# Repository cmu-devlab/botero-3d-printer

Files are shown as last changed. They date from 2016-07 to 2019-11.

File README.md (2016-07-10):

# Botero 3D Printer Construction
******WORK-IN-PROGRESS******
  - Contents
    - `./drivers`: USB drivers for the Arduino Mega with CH340g chipset
    - `./firmware`: files for loading firmware onto the Arduino Mega + RAMPS 1.4 board
    - `./printer-parts`: laser-cut and 3d printable part files
  - Guides
    - [Bill of Materials](https://docs.google.com/spreadsheets/d/1qfAnqGb2Y4jCnc3KZLQFH8dfTMAcHStBsM3m4sgjOxE/edit?usp=sharing)
    - [Preliminary (incomplete) Instructions](https://docs.google.com/document/d/1Rjcu9FiFy42U2eL0eWIAQUI9wFf0EVY7zgJ4SKwblW4/edit)

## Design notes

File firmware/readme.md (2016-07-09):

# Firmware Setup Instructions
- Visit https://www.repetier.com/firmware/v092/
- Upload the `repetier-firmware-base-config-v092_9.json` file. You can use these settings to help calibrate your printer and its dimensions later
- Go through the configuration wizard and set the BAUD_RATE to 115200 for compatability with Macs and Windows OS. If you are only using Windows-based OS, you can use 250000.

* If you're having trouble connecting to device in Repeiter Host after installing the printer firmware, ensure your firmware is compiled with a `BAUD_RATE` of `115200`.

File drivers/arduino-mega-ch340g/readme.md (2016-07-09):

# Arduino CH340g Driver Installation
These drivers are available for convenience to install the chipset CH340/1 arduino boards.

### Mac OS >= 10.9 Instructions
  - Plug in the device.
  - Locate and install the driver `CH34x_Install.pkg` within the Mac OS drivers folder `./path_to_repository/drivers/arduino-mega-ch340g/mac-osx-10_9-or-higher`.
  - Once finished restart your computer.
  - Plug in your device if it isn't already plugged in.
  - Open a terminal window and type `ls /dev/tty*`. 
  - If the driver properly installed you should see a device like `tty.wchusbserial`. 

### Windows >= 8 Instructions
  - `Note: This driver is for CH340, CH340G & CH341 (USB-SERIAL chip) V3.4 Driver Version = 08/08/2014, 3.4.2014.08.`
  - Plug the Arduino Mega into USB port
  - Open Device Manager > under `Other Devices`, there should be something recognized as "USB2.0-Serial" with an exclamation mark. Right click and select `Update Driver Software`.
  - Select `Browse my computer for driver software`
  - Locate and select the top-level driver folder in the Windows 8 or greater folder of this direction: `./path_to_repository/drivers/win8-or-greater/CH341SER`
  - Complete the installation - once the installer finishes, you should see USB-SERIAL CH340 as being recognized.
  - In Device Manager, this device should be listed under `Ports (COM & LPT)`.

### Sources
- Original Drivers can be found on http://www.wch.cn/download/CH341SER_ZIP.html
- Windows >= 8 Instructions :http://www.arduined.eu/ch340-windows-8-driver-download/

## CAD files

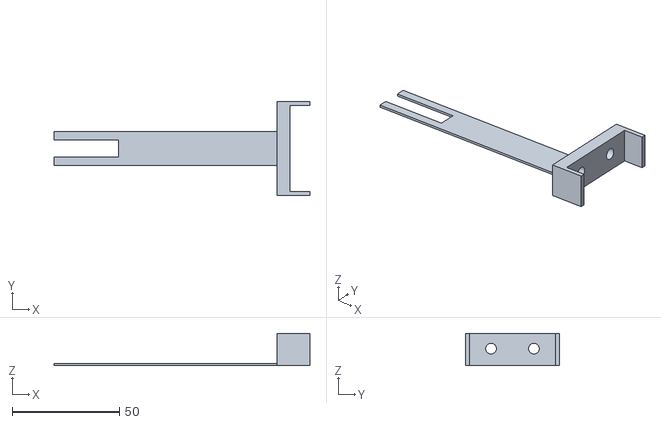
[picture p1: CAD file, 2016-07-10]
printer-parts/alignment-guide/alignment_guide.stl
119.4 x 44.0 x 15.0

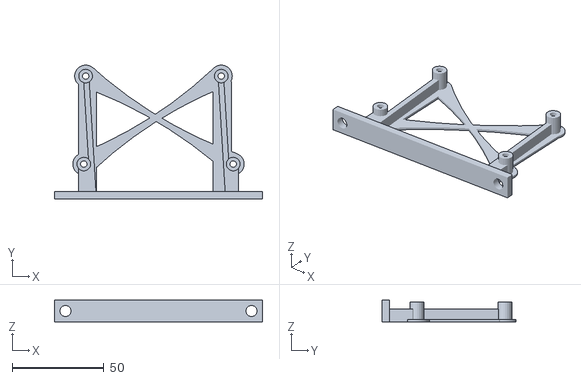
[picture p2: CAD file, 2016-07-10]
printer-parts/arduino-t-slot-mount/Arduino_T-Slot_Mount_mod1.stl
113.5 x 73.0 x 12.0

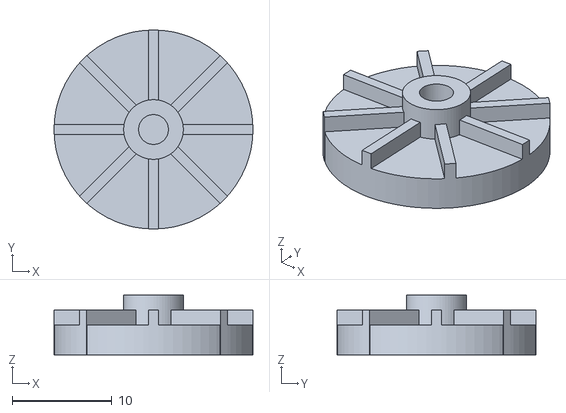
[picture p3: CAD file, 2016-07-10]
printer-parts/end-stop-bumper/endstop_bumper_v2.stl
20.0 x 20.0 x 6.00

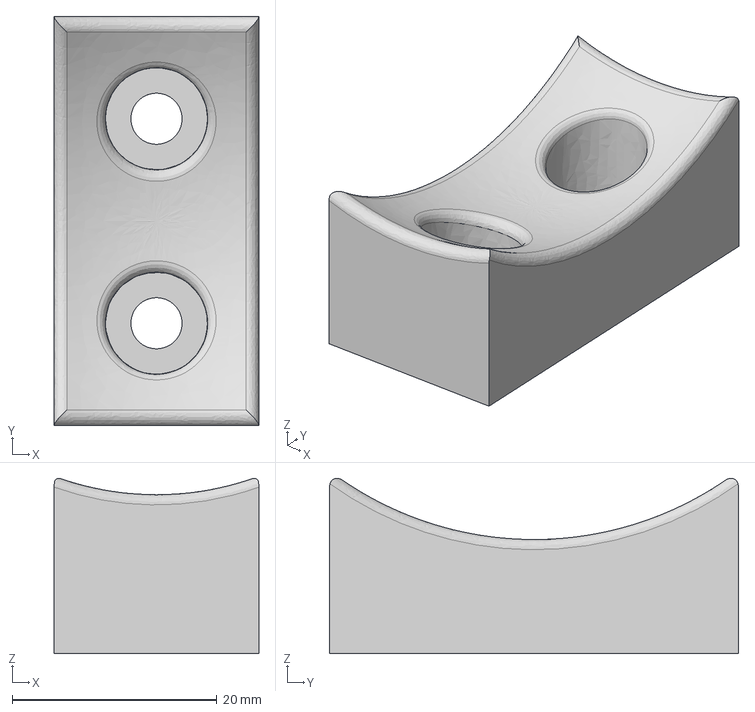
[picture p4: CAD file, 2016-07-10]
printer-parts/foot/tennis-ball-foot-holder/tennis_ball_foot_bracket_v1 v1.iges
20.0 x 40.0 x 17.1 mm

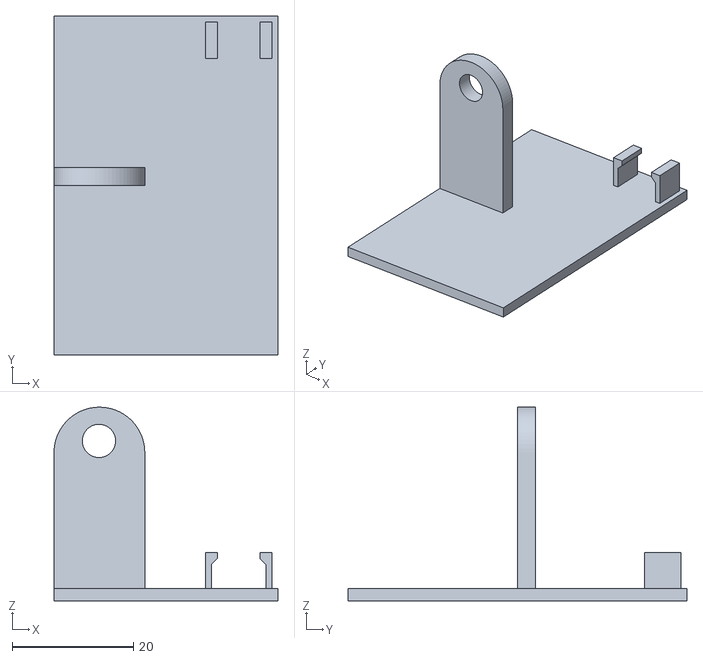
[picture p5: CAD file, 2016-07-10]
printer-parts/led-holder/LED_plate_v3.stl
37.0 x 56.0 x 32.0

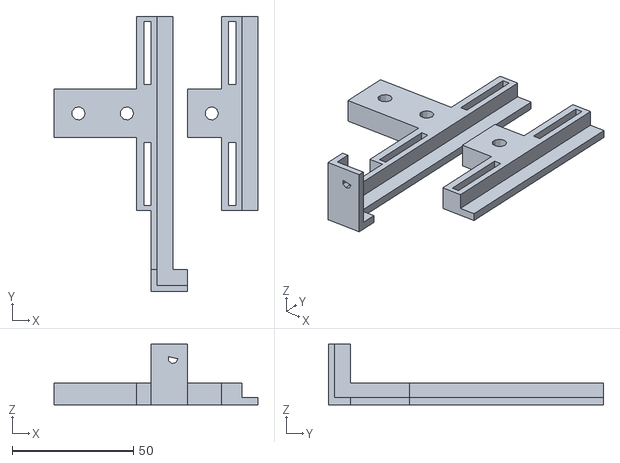
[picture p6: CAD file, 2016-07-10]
printer-parts/power-supply-holder/ps_holder4.stl
84.0 x 113.5 x 25.0

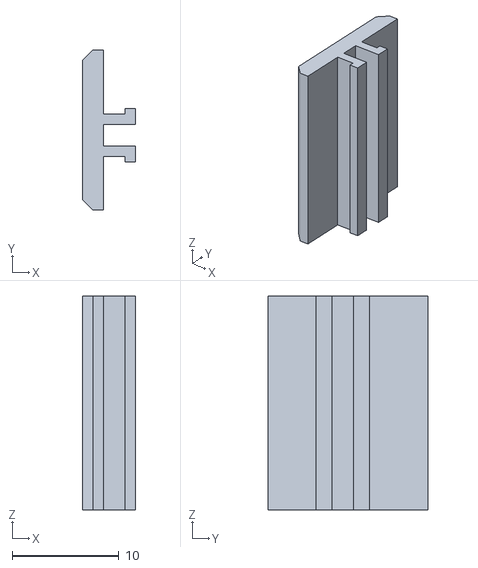
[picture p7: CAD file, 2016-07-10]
printer-parts/t-slot-cable-cover/t-slot_cable_cover.stl
5.00 x 15.0 x 20.0

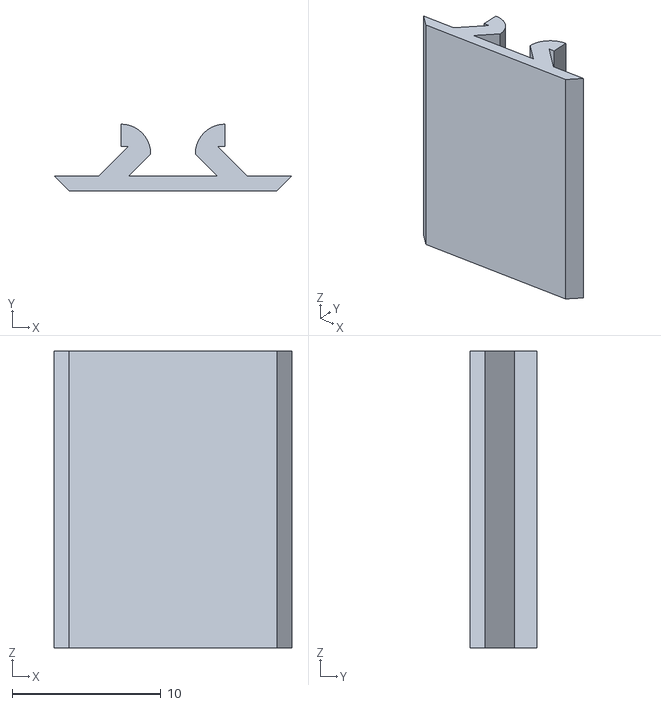
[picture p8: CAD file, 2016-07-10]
printer-parts/v-slot-cable-cover/V-slot_2020_cable_cover.STL
16.0 x 4.50 x 20.0

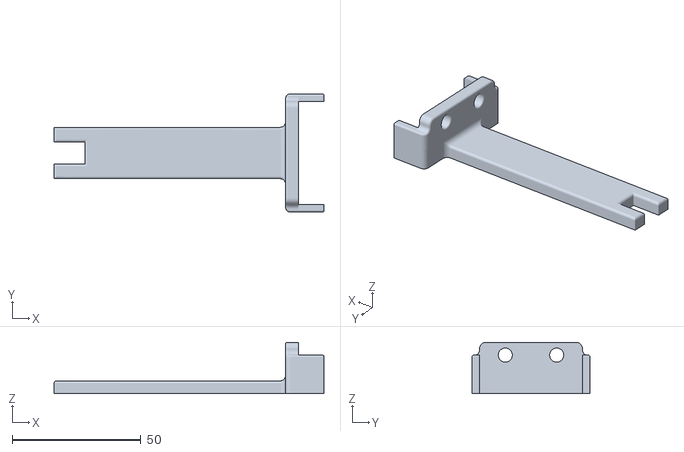
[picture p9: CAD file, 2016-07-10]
printer-parts/z-axis-centering-jig/z_axis_centering_jig_v1.stl
105.0 x 46.0 x 20.0

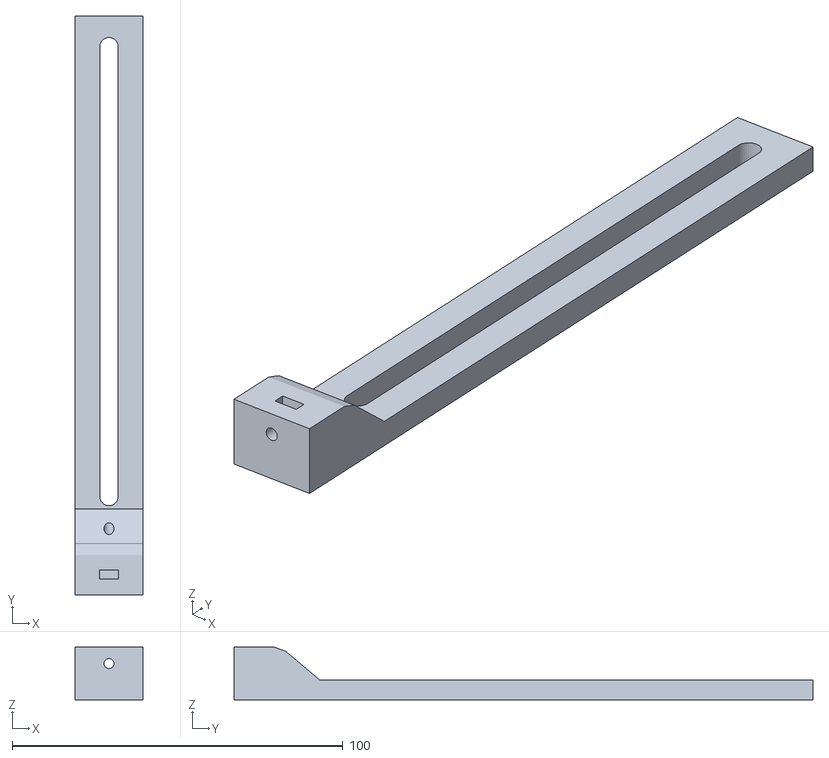
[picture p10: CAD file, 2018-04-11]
printer-parts/z-axis-end-stop-plunger/z-endstop-mr/z-endstop-v1.stl
20.5 x 175.0 x 16.0

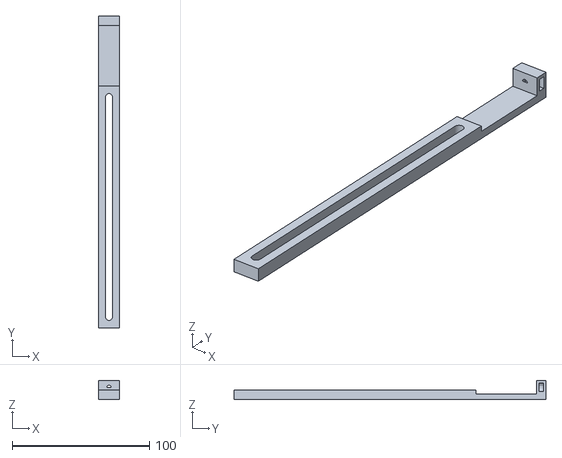
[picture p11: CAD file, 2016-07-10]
printer-parts/z-axis-end-stop-plunger/z_endstop_plunger.stl
15.0 x 227.0 x 14.0

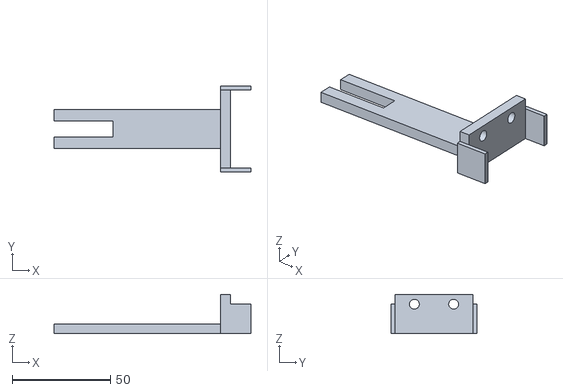
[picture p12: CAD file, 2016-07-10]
printer-parts/alignment-guide/alignment_guide_v2.stl
100.4 x 44.0 x 20.0

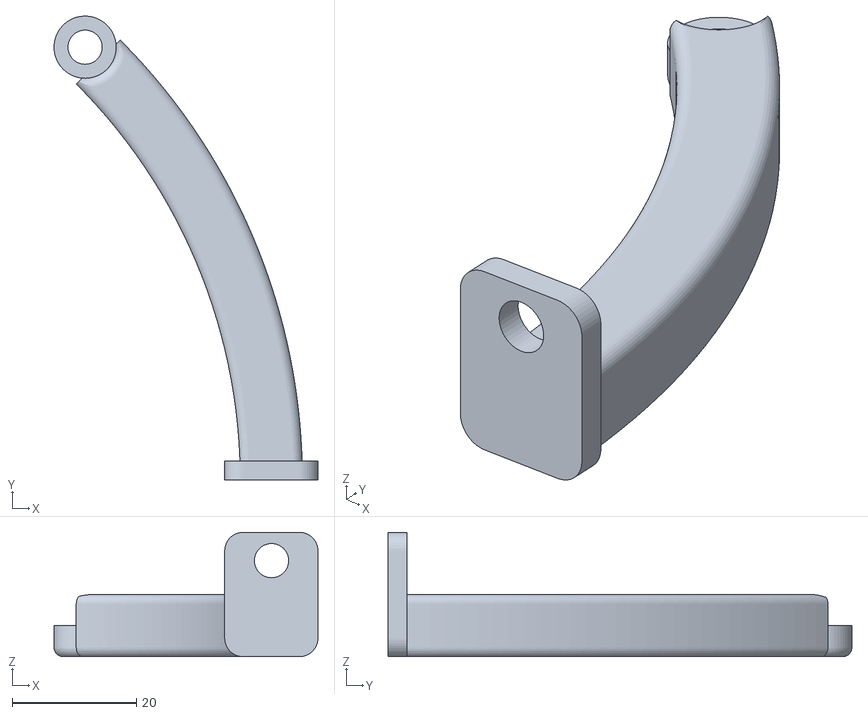
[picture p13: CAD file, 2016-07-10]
printer-parts/led-holder/LED_arm1_v4.stl
42.4 x 74.6 x 20.0

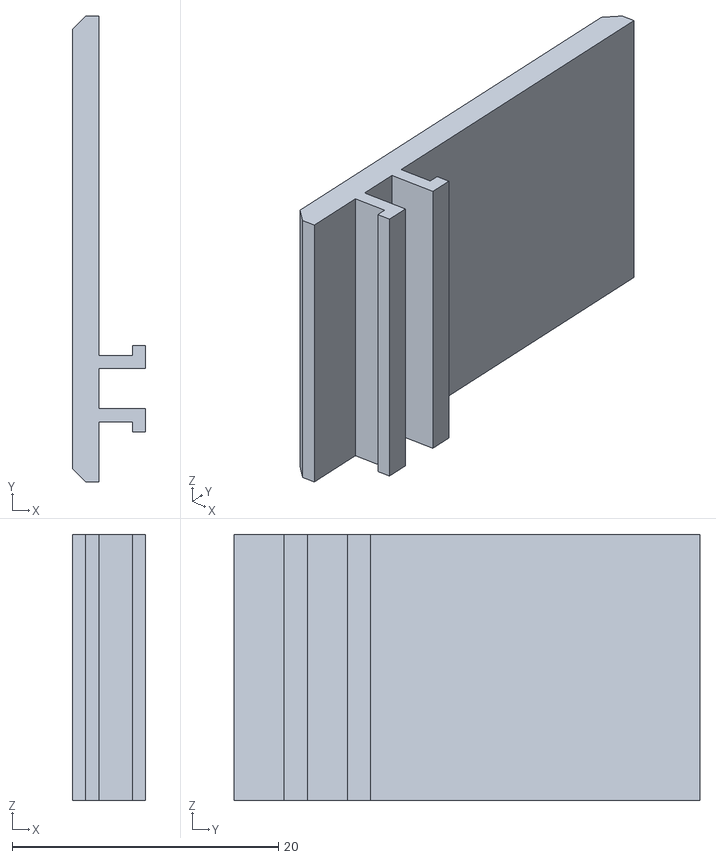
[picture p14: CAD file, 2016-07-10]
printer-parts/t-slot-cable-cover/t-slot_cable_cover_v2_double_wide.stl
5.50 x 35.0 x 20.0

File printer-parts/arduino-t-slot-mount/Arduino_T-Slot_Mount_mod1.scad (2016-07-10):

holes_size = 1.75; // Radius
holes_size_outter = 3.75; // Radius
holes_support = 11;
$fn=100;

difference() {
	union() {
		translate([70.5,0,0]) {
			translate([0,-17,0]) {
				translate([17,0,0])rotate([0,0,180])t_slot();
				cube([10,62,1.3]);
			}
			translate([6.8,-18,0])rotate([0,0,3.5])cube([3,63,holes_support*.65]);
		}

		translate([-3,0,0]) {
			translate([0,-17,0]) {
				translate([-3,0,0])t_slot();
				cube([10,62,1.3]);
			}
			translate([6.8,-18,0])rotate([0,0,3.5])cube([3,63,holes_support*.65]);
		}

		translate([3,-19,0])cube([75,4,12]);

		#translate([-3,-19,0])cube([7.5,18,7.15]);
		#translate([77,-19,0])cube([7.5,18,7.15]);

		arduino_holes();

		linear_extrude(height=1.3)barbell([75,48],[0,0],6,6,230,230);
		linear_extrude(height=1.3)barbell([81.5,0],[1,48],6,6,240,240);
	}
	union() {
		// Holes
		//RB
			cylinder(r=holes_size,h=holes_support, $fn=20);
		//LB
			translate([1,48,0])cylinder(r=holes_size,h=holes_support, $fn=20);
		//RT
			translate([81.5,0,0])cylinder(r=holes_size,h=holes_support, $fn=20);
		//LT
			translate([75,48,0])cylinder(r=holes_size,h=holes_support, $fn=20);
	}
}




module arduino_holes() {
difference() {

union() {
// Outter
//RB
	cylinder(r=holes_size_outter,h=holes_support, $fn=20);
//LB
	translate([1,48,0])cylinder(r=holes_size_outter,h=holes_support, $fn=20);
//RT
	translate([81.5,0,0])cylinder(r=holes_size_outter,h=holes_support, $fn=20);
//LT
	translate([75,48,0])cylinder(r=holes_size_outter,h=holes_support, $fn=20);
}
// Holes
//RB
	cylinder(r=holes_size,h=holes_support, $fn=20);
//LB
	translate([1,48,0])cylinder(r=holes_size,h=holes_support, $fn=20);
//RT
	translate([81.5,0,0])cylinder(r=holes_size,h=holes_support, $fn=20);
//LT
	translate([75,48,0])cylinder(r=holes_size,h=holes_support, $fn=20);
}

}

module t_slot() {

	difference() {
		translate([0,0,6])cube([20,4,12],true);
		translate([-4,3,6])rotate([90,0,0])cylinder(r=3, h=10);
	}

}


module barbell (x1,x2,r1,r2,r3,r4) 
{
	x3=triangulate (x1,x2,r1+r3,r2+r3);
	x4=triangulate (x2,x1,r2+r4,r1+r4);
	render()
	difference ()
	{
		union()
		{
			translate(x1)
			circle (r=r1);
			translate(x2)
			circle(r=r2);
			polygon (points=[x1,x3,x2,x4]);
		}
		translate(x3)
		circle(r=r3,$fa=5);
		translate(x4)
		circle(r=r4,$fa=5);
	}
}

function triangulate (point1, point2, length1, length2) = 
point1 + 
length1*rotated(
atan2(point2[1]-point1[1],point2[0]-point1[0])+
angle(distance(point1,point2),length1,length2));

function distance(point1,point2)=
sqrt((point1[0]-point2[0])*(point1[0]-point2[0])+
(point1[1]-point2[1])*(point1[1]-point2[1]));

function angle(a,b,c) = acos((a*a+b*b-c*c)/(2*a*b)); 

function rotated(a)=[cos(a),sin(a),0];

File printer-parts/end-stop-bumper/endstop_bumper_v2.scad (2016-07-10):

$fn=64;
difference() {
	union() {
		cylinder(r=20/2,h=3);
		cylinder(r=6/2, h=6);
		for (angle=[0:45:359.99]) {
			rotate([0,0,angle]) 
			translate([-10,-0.5,0]) 
				cube([20,1,4.5]);
		}
	}
	translate([0,0,1]) cylinder(r=3.0/2, h=6);
}

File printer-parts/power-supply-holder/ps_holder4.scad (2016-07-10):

ps_slip = 1;
ps_h = 86+ps_slip;
ps_w = 150+ps_slip;
ps_len = 140+ps_slip;
hole_bl = [6,16];
hole_br = [ps_w-30, 6];
hole_tl = [6, ps_h-6];
hole_tr = [ps_w-6, ps_h-6];
hole_diam = 4;
hole_pad = 12;
wall = 3;
beam = 6;
hanger_len = 20; // single wide
hanger_w = 20*2; // two tall
hanger_thick = beam+wall;
hanger_hole_diam = 5.5;
hanger_hole_offset = 10;
hanger_hole_spacing = 20;
strap_w = 30;
strap_margin = 2;
strap_holder_sz = 6;
strap_slot = 3;


module top_mount() {
	difference() {
		translate([-wall,-wall,-wall]) 
		union() {
			// block for bar across
			cube([beam+wall, wall+ps_len/2+hanger_len/2+strap_w, beam+wall]);
			// beam going around corner and up to left hole
			cube([beam+wall+hole_pad/2, beam+wall, hole_bl[1]+hole_pad/2+wall]);
			// right strap holder
			translate([-strap_holder_sz,wall+ps_len/2+hanger_len/2,0])
				difference() {
					cube([strap_holder_sz,strap_w,beam+wall]);
					translate([strap_holder_sz/2-strap_slot/2+wall/2,strap_margin,0])
						cube([strap_slot,strap_w-2*strap_margin,beam+wall]);
				}
			// left strap holder
			translate([-strap_holder_sz,wall+ps_len/2-hanger_len/2-strap_w,0])
				difference() {
					cube([strap_holder_sz,strap_w,beam+wall]);
					translate([strap_holder_sz/2-strap_slot/2+wall/2,strap_margin,0])
						cube([strap_slot,strap_w-2*strap_margin,beam+wall]);
				}
			// hanger
			translate([-(hanger_w), ps_len/2-hanger_len/2+wall, 0]) 
				difference() {
					cube([hanger_w,hanger_len,hanger_thick]);
					for (row = [0:1]) 
						for (col = [0:1])
							translate([
									hanger_hole_offset+row*hanger_hole_spacing, 
									hanger_hole_offset+col*hanger_hole_spacing,0]) 
								cylinder(r=hanger_hole_diam/2, h=hanger_thick);
				}
		}
		// cut out for body of PS
		translate([-ps_slip/2,-ps_slip/2,0]) cube([ps_w,ps_len,ps_h]);
		// cut through so bottom of base is open instead of solid
		translate([beam,beam,-wall]) cube([ps_w-2*beam,ps_len-2*beam,ps_h]);
		// drill mounting hole
		translate([hole_bl[0],0,hole_bl[1]]) rotate([90,0,0]) 
			cylinder(r=hole_diam/2, h=wall);
	}
}

module bottom_mount() {
	difference() {
		translate([-wall,-wall,-wall]) 
		union() {
			// block for bar across
			translate([0,ps_len/2-hanger_len/2-strap_w+wall,0])
				cube([beam+wall, hanger_len+strap_w*2, beam+wall]);
			// right strap holder
			translate([-strap_holder_sz,wall+ps_len/2+hanger_len/2,0])
				difference() {
					cube([strap_holder_sz,strap_w,beam+wall]);
					translate([strap_holder_sz/2-strap_slot/2+wall/2,strap_margin,0])
						cube([strap_slot,strap_w-2*strap_margin,beam+wall]);
				}
			// left strap holder
			translate([-strap_holder_sz,wall+ps_len/2-hanger_len/2-strap_w,0])
				difference() {
					cube([strap_holder_sz,strap_w,beam+wall]);
					translate([strap_holder_sz/2-strap_slot/2+wall/2,strap_margin,0])
						cube([strap_slot,strap_w-2*strap_margin,beam+wall]);
				}
			// hanger
			translate([-hanger_w/2, ps_len/2-hanger_len/2+wall, 0]) 
				difference() {
					cube([hanger_w/2,hanger_len,hanger_thick]);
					translate([-hanger_hole_offset+hanger_hole_spacing, 
									hanger_hole_offset,0]) 
								cylinder(r=hanger_hole_diam/2, h=hanger_thick);
				}
		}
		// cut out for body of PS
		translate([-ps_slip/2,-ps_slip/2,0]) cube([ps_w,ps_len,ps_h]);
		// cut through so bottom of base is open instead of solid
		translate([beam,beam,-wall]) cube([ps_w-2*beam,ps_len-2*beam,ps_h]);
	}
}

top_mount();
// bottom_mount();
translate([35,0,0]) bottom_mount();

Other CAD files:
printer-parts/t-slot-cable-cover/t-slot_cable_cover_v2.stl
printer-parts/t-slot-cable-cover/t-slot_cable_cover_v1.iges
printer-parts/led-holder/LED_arm2_v4.stl
printer-parts/led-holder/led_brackets_v2.stl
printer-parts/z-axis-end-stop-plunger/z_endstop_plunger.scad
printer-parts/alignment-guide/alignment_guide.3dm
printer-parts/alignment-guide/alignment_guide_v2.3dm
printer-parts/foot/tennis-ball-foot-holder/tennis_ball_foot_holder_v1.3dm
printer-parts/led-holder/LED Brackets v3.f3d
printer-parts/led-holder/LED_arm1_v3.stl
printer-parts/led-holder/LED_arm2_v3.stl
printer-parts/previous-designs/z_axis_nut_holder_v4.scad
printer-parts/previous-designs/z_axis_nut_holder_v4.stl
printer-parts/t-slot-cable-cover/t-slot_cable_cover_v2.f3d
printer-parts/t-slot-cable-cover/t-slot_cable_cover_v2_double_wide v0.f3d
printer-parts/z-axis-centering-jig/z-axis_centering_jig_v1.f3d
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

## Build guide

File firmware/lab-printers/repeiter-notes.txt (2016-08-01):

X/Y refer to the

Distortion refers to the region in which the extruder is allowed to move during the printing process

BED_LEFT = DISTORTION_XMIN
BED_WIDTH = DISTORTION_XMAX - DISTORTION_XMIN 

BED_FRONT = DISTORTION_YMIN
BED_DEPTH = DISTORTION_YMAX - DISTORTION_YMIN 

112 0921

IF you want to use 2 heaters (Heat 2 on board / dual extruders) you must disable the fan driving in the firmware.
Namely set `FEATURE_FAN_CONTROL` to 0. 
#define FEATURE_FAN_CONTROL 0

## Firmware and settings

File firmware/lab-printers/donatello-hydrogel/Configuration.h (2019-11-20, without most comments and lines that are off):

#define CONFIGURATION_H
#define NUM_EXTRUDER 2
#define MOTHERBOARD 33
#include "pins.h"
#undef FAN_BOARD_PIN
#define FAN_BOARD_PIN HEATER_2_PIN
#define BOARD_FAN_SPEED 255
#define FAN_THERMO_PIN -1
#define FAN_THERMO_MIN_PWM 128
#define FAN_THERMO_MAX_PWM 255
#define FAN_THERMO_MIN_TEMP 45
#define FAN_THERMO_MAX_TEMP 60
#define FAN_THERMO_THERMISTOR_PIN -1
#define FAN_THERMO_THERMISTOR_TYPE 1
#define BLUETOOTH_SERIAL  -1
#define BLUETOOTH_BAUD  115200
#define MIXING_EXTRUDER 0
#define DRIVE_SYSTEM 0
#define XAXIS_STEPS_PER_MM 160       //OK
#define YAXIS_STEPS_PER_MM 160       //OK
#define ZAXIS_STEPS_PER_MM 800      //OK
#define EXTRUDER_FAN_COOL_TEMP 50
#define PDM_FOR_EXTRUDER 0
#define PDM_FOR_COOLER 0
#define DECOUPLING_TEST_MAX_HOLD_VARIANCE 20
#define DECOUPLING_TEST_MIN_TEMP_RISE 1
#define KILL_IF_SENSOR_DEFECT 0
#define RETRACT_ON_PAUSE 2
#define PAUSE_START_COMMANDS ""
#define PAUSE_END_COMMANDS ""
#define SHARED_EXTRUDER_HEATER 0
#define EXT0_X_OFFSET 0
#define EXT0_Y_OFFSET 0
#define EXT0_Z_OFFSET 0
#define EXT0_STEPS_PER_MM 184    //OK
#define EXT0_TEMPSENSOR_TYPE 1
#define EXT0_TEMPSENSOR_PIN TEMP_0_PIN
#define EXT0_HEATER_PIN HEATER_0_PIN
#define EXT0_STEP_PIN ORIG_E0_STEP_PIN
#define EXT0_DIR_PIN ORIG_E0_DIR_PIN
#define EXT0_INVERSE 1
#define EXT0_ENABLE_PIN ORIG_E0_ENABLE_PIN
#define EXT0_ENABLE_ON 0
#define EXT0_MIRROR_STEPPER 0
#define EXT0_STEP2_PIN ORIG_E0_STEP_PIN
#define EXT0_DIR2_PIN ORIG_E0_DIR_PIN
#define EXT0_INVERSE2 0
#define EXT0_ENABLE2_PIN ORIG_E0_ENABLE_PIN
#define EXT0_MAX_FEEDRATE 50
#define EXT0_MAX_START_FEEDRATE 20
#define EXT0_MAX_ACCELERATION 5000
#define EXT0_HEAT_MANAGER 3
#define EXT0_WATCHPERIOD 1
#define EXT0_PID_INTEGRAL_DRIVE_MAX 230
#define EXT0_PID_INTEGRAL_DRIVE_MIN 40
#define EXT0_PID_PGAIN_OR_DEAD_TIME 7
#define EXT0_PID_I 2
#define EXT0_PID_D 40
#define EXT0_PID_MAX 255
#define EXT0_ADVANCE_K 0
#define EXT0_ADVANCE_L 0
#define EXT0_ADVANCE_BACKLASH_STEPS 0
#define EXT0_WAIT_RETRACT_TEMP 150
#define EXT0_WAIT_RETRACT_UNITS 0
#define EXT0_SELECT_COMMANDS ""
#define EXT0_DESELECT_COMMANDS ""
#define EXT0_EXTRUDER_COOLER_PIN -1
#define EXT0_EXTRUDER_COOLER_SPEED 255
#define EXT0_DECOUPLE_TEST_PERIOD 12000
#define EXT0_JAM_PIN -1
#define EXT0_JAM_PULLUP 0
#define EXT1_STEPS_PER_MM  9255.38 // 9517.188 // assumes 16 usteps ; probably need to adjust?
#define EXT1_X_OFFSET (41200 * XAXIS_STEPS_PER_MM)/1000  // better precision with integers :)
#define EXT1_Y_OFFSET 0
#define EXT1_Z_OFFSET 0
#define EXT1_TEMPSENSOR_TYPE 1   // 1
#define EXT1_TEMPSENSOR_PIN  TEMP_1_PIN    // TEMP_0_PIN
#define EXT1_HEATER_PIN HEATER_1_PIN
#define EXT1_STEP_PIN ORIG_E1_STEP_PIN
#define EXT1_DIR_PIN ORIG_E1_DIR_PIN
#define EXT1_INVERSE 0
#define EXT1_ENABLE_PIN ORIG_E1_ENABLE_PIN
#define EXT1_ENABLE_ON 0
#define EXT1_MIRROR_STEPPER 0
#define EXT1_STEP2_PIN ORIG_E1_STEP_PIN
#define EXT1_DIR2_PIN ORIG_E1_DIR_PIN
#define EXT1_INVERSE2 0
#define EXT1_ENABLE2_PIN ORIG_E1_ENABLE_PIN
#define EXT1_MAX_FEEDRATE 50
#define EXT1_MAX_START_FEEDRATE 20
#define EXT1_MAX_ACCELERATION 5000
#define EXT1_HEAT_MANAGER 3
#define EXT1_WATCHPERIOD 1
#define EXT1_PID_INTEGRAL_DRIVE_MAX 230
#define EXT1_PID_INTEGRAL_DRIVE_MIN 40
#define EXT1_PID_PGAIN_OR_DEAD_TIME 6.72 // 7
#define EXT1_PID_I 0.26 //2
#define EXT1_PID_D 44.01 // 40
#define EXT1_PID_MAX 255
#define EXT1_ADVANCE_K 0
#define EXT1_ADVANCE_L 0
#define EXT1_ADVANCE_BACKLASH_STEPS 0
#define EXT1_WAIT_RETRACT_TEMP 150
#define EXT1_WAIT_RETRACT_UNITS 0
#define EXT1_SELECT_COMMANDS ""
#define EXT1_DESELECT_COMMANDS ""
#define EXT1_EXTRUDER_COOLER_PIN -1
#define EXT1_EXTRUDER_COOLER_SPEED 255
#define EXT1_DECOUPLE_TEST_PERIOD EXT0_DECOUPLE_TEST_PERIOD
#define EXT1_JAM_PIN -1
#define EXT1_JAM_PULLUP 0
#define FEATURE_RETRACTION 0
#define AUTORETRACT_ENABLED 0
#define RETRACTION_LENGTH 3
#define RETRACTION_LONG_LENGTH 13
#define RETRACTION_SPEED 40
#define RETRACTION_Z_LIFT 0
#define RETRACTION_UNDO_EXTRA_LENGTH 0
#define RETRACTION_UNDO_EXTRA_LONG_LENGTH 0
#define RETRACTION_UNDO_SPEED 20
#define FILAMENTCHANGE_X_POS 0
#define FILAMENTCHANGE_Y_POS 0
#define FILAMENTCHANGE_Z_ADD  2
#define FILAMENTCHANGE_REHOME 1
#define FILAMENTCHANGE_SHORTRETRACT 5
#define FILAMENTCHANGE_LONGRETRACT 50
#define JAM_STEPS 220
#define JAM_SLOWDOWN_STEPS 320
#define JAM_SLOWDOWN_TO 70
#define JAM_ERROR_STEPS 500
#define JAM_MIN_STEPS 10
#define JAM_ACTION 1
#define RETRACT_DURING_HEATUP true
#define PID_CONTROL_RANGE 20
#define SKIP_M109_IF_WITHIN 2
#define SCALE_PID_TO_MAX 0
#define TEMP_HYSTERESIS 0
#define EXTRUDE_MAXLENGTH 160
#define NUM_TEMPS_USERTHERMISTOR0 0
#define USER_THERMISTORTABLE0 {}
#define NUM_TEMPS_USERTHERMISTOR1 0
#define USER_THERMISTORTABLE1 {}
#define NUM_TEMPS_USERTHERMISTOR2 0
#define USER_THERMISTORTABLE2 {}
#define GENERIC_THERM_VREF 5
#define GENERIC_THERM_NUM_ENTRIES 33
#define HEATER_PWM_SPEED 0
#define HAVE_HEATED_BED 0
#define HEATED_BED_MAX_TEMP 120
#define SKIP_M190_IF_WITHIN 3
#define HEATED_BED_SENSOR_TYPE 1
#define HEATED_BED_SENSOR_PIN TEMP_1_PIN
#define HEATED_BED_HEATER_PIN HEATER_1_PIN
#define HEATED_BED_SET_INTERVAL 5000
#define HEATED_BED_HEAT_MANAGER 0
#define HEATED_BED_PID_INTEGRAL_DRIVE_MAX 255
#define HEATED_BED_PID_INTEGRAL_DRIVE_MIN 80
#define HEATED_BED_PID_PGAIN_OR_DEAD_TIME   196
#define HEATED_BED_PID_IGAIN   33
#define HEATED_BED_PID_DGAIN 290
#define HEATED_BED_PID_MAX 255
#define HEATED_BED_DECOUPLE_TEST_PERIOD 300000
#define MIN_EXTRUDER_TEMP 40
#define MAXTEMP 275
#define MIN_DEFECT_TEMPERATURE -10
#define MAX_DEFECT_TEMPERATURE 290
#define SUPPORT_LASER 0
#define LASER_PIN -1
#define LASER_ON_HIGH 1
#define SUPPORT_CNC 0
#define CNC_WAIT_ON_ENABLE 300
#define CNC_WAIT_ON_DISABLE 0
#define CNC_ENABLE_PIN -1
#define CNC_ENABLE_WITH 1
#define CNC_DIRECTION_PIN -1
#define CNC_DIRECTION_CW 1
#define DEFAULT_PRINTER_MODE 0
#define ENDSTOP_PULLUP_X_MIN true
#define ENDSTOP_X_MIN_INVERTING false
#define MIN_HARDWARE_ENDSTOP_X true
#define ENDSTOP_PULLUP_Y_MIN true
#define ENDSTOP_Y_MIN_INVERTING true
#define MIN_HARDWARE_ENDSTOP_Y true
#define ENDSTOP_PULLUP_Z_MIN true
#define ENDSTOP_Z_MIN_INVERTING true
#define MIN_HARDWARE_ENDSTOP_Z true
#define ENDSTOP_PULLUP_X_MAX true
#define ENDSTOP_X_MAX_INVERTING false
#define MAX_HARDWARE_ENDSTOP_X false
#define ENDSTOP_PULLUP_Y_MAX true
#define ENDSTOP_Y_MAX_INVERTING false
#define MAX_HARDWARE_ENDSTOP_Y false
#define ENDSTOP_PULLUP_Z_MAX true
#define ENDSTOP_Z_MAX_INVERTING false
#define MAX_HARDWARE_ENDSTOP_Y false
#define MAX_HARDWARE_ENDSTOP_Z false
#define max_software_endstop_r true
#define min_software_endstop_x false
#define min_software_endstop_y false
#define min_software_endstop_z false
#define max_software_endstop_x true
#define max_software_endstop_y true
#define max_software_endstop_z true
#define ALWAYS_CHECK_ENDSTOPS 1
#define ENDSTOP_X_BACK_MOVE 5
#define ENDSTOP_Y_BACK_MOVE 5
#define ENDSTOP_Z_BACK_MOVE 2
#define ENDSTOP_X_RETEST_REDUCTION_FACTOR 3
#define ENDSTOP_Y_RETEST_REDUCTION_FACTOR 3
#define ENDSTOP_Z_RETEST_REDUCTION_FACTOR 3
#define ENDSTOP_X_BACK_ON_HOME 0
#define ENDSTOP_Y_BACK_ON_HOME 0
#define ENDSTOP_Z_BACK_ON_HOME 0.5
#define ALWAYS_CHECK_ENDSTOPS 1
#define X_ENABLE_ON 0
#define Y_ENABLE_ON 0
#define Z_ENABLE_ON 0
#define DISABLE_X 0
#define DISABLE_Y 0
#define DISABLE_Z 0
#define DISABLE_E 0
#define INVERT_X_DIR 1
#define INVERT_Y_DIR 1
#define INVERT_Z_DIR 1
#define X_HOME_DIR -1
#define Y_HOME_DIR -1
#define Z_HOME_DIR -1
#define X_MAX_LENGTH 530  //OK
#define Y_MAX_LENGTH 160  //OK
#define Z_MAX_LENGTH 140  //OK
#define X_MIN_POS 0
#define Y_MIN_POS 0
#define Z_MIN_POS 0
#define PRINTER_BED_WIDTH 175
#define PRINTER_BED_DEPTH 160
#define DISTORTION_CORRECTION 0
#define DISTORTION_CORRECTION_POINTS 5
#define DISTORTION_CORRECTION_R 100
#define DISTORTION_PERMANENT 0
#define DISTORTION_UPDATE_FREQUENCY 15
#define DISTORTION_START_DEGRADE 0.5
#define DISTORTION_END_HEIGHT 1
#define DISTORTION_EXTRAPOLATE_CORNERS 0
#define DISTORTION_XMIN 220   //OK
#define DISTORTION_YMIN 0   //OK
#define DISTORTION_XMAX DISTORTION_XMIN + PRINTER_BED_WIDTH
#define DISTORTION_YMAX DISTORTION_YMIN + PRINTER_BED_DEPTH
#define FEATURE_BABYSTEPPING 1
#define BABYSTEP_MULTIPLICATOR 1
#define DELTA_SEGMENTS_PER_SECOND_PRINT 180 // Move accurate setting for print moves
#define DELTA_SEGMENTS_PER_SECOND_MOVE 70 // Less accurate setting for other moves
#define EXACT_DELTA_MOVES 1
#define DELTA_HOME_ON_POWER 0
#define DELTASEGMENTS_PER_PRINTLINE 24
#define STEPPER_INACTIVE_TIME 360L
#define MAX_INACTIVE_TIME 0L
#define MAX_FEEDRATE_X 300
#define MAX_FEEDRATE_Y 300
#define MAX_FEEDRATE_Z 2
#define HOMING_FEEDRATE_X 40
#define HOMING_FEEDRATE_Y 40
#define HOMING_FEEDRATE_Z 2
#define HOMING_ORDER HOME_ORDER_XYZ
#define ZHOME_MIN_TEMPERATURE 0
#define ZHOME_HEAT_ALL 1
#define ZHOME_HEAT_HEIGHT 20
#define ZHOME_X_POS 999999
#define ZHOME_Y_POS 999999
#define ENABLE_BACKLASH_COMPENSATION 0
#define X_BACKLASH 0
#define Y_BACKLASH 0
#define Z_BACKLASH 0
#define RAMP_ACCELERATION 1
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

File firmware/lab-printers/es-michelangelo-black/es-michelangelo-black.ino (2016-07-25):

/*
    This file is part of Repetier-Firmware.

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
    This firmware is a nearly complete rewrite of the sprinter firmware
    by kliment (https://github.com/kliment/Sprinter)
    which based on Tonokip RepRap firmware rewrite based off of Hydra-mmm firmware.

    Main author: repetier

*/
/**
\mainpage Repetier-Firmware for Arduino based RepRaps
<CENTER>Copyright &copy; 2011-2013 by repetier
</CENTER>

\section Intro Introduction


\section GCodes Implemented GCodes

 look here for descriptions of gcodes: http://linuxcnc.org/handbook/gcode/g-code.html
 and http://objects.reprap.org/wiki/Mendel_User_Manual:_RepRapGCodes

Implemented Codes

- G0  -> G1
- G1  - Coordinated Movement X Y Z E, S1 disables boundary check, S0 enables it
- G4  - Dwell S<seconds> or P<milliseconds>
- G10 S<1 = long retract, 0 = short retract = default> retracts filament according to stored setting
- G11 S<1 = long retract, 0 = short retract = default> = Undo retraction according to stored setting
- G20 - Units for G0/G1 are inches.
- G21 - Units for G0/G1 are mm.
- G28 - Home all axis or named axis.
- G29 S<0..2> - Z-Probe at the 3 defined probe points. S = 1 measure avg. zHeight, S = 2 store avg zHeight
- G30 P<0..3> - Single z-probe at current position P = 1 first measurement, P = 2 Last measurement P = 0 or 3 first and last measurement
- G31 - Write signal of probe sensor
- G32 S<0..2> P<0..1> - Autolevel print bed. S = 1 measure zLength, S = 2 Measure and store new zLength
- G90 - Use absolute coordinates
- G91 - Use relative coordinates
- G92 - Set current position to coordinates given
- G131 - set extruder offset position to 0 - needed for calibration with G132
- G132 - calibrate endstop positions. Call this, after calling G131 and after centering the extruder holder.
- G133 - measure steps until max endstops for deltas. Can be used to detect lost steps within tolerances of endstops.
- G134 Px Sx Zx - Calibrate nozzle height difference (need z probe in nozzle!) Px = reference extruder, Sx = only measure extrude x against reference, Zx = add to measured z distance for Sx for correction.

RepRap M Codes

- M104 - Set extruder target temp
- M105 - Read current temp
- M106 S<speed> P<fan> - Fan on speed = 0..255, P = 0 or 1, 0 is default and can be omitted
- M107 P<fan> - Fan off, P = 0 or 1, 0 is default and can be omitted
- M109 - Wait for extruder current temp to reach target temp.
- M114 - Display current position

Custom M Codes

- M20  - List SD card
- M21  - Init SD card
- M22  - Release SD card
- M23  - Select SD file (M23 filename.g)
- M24  - Start/resume SD print
- M25  - Pause SD print
- M26  - Set SD position in bytes (M26 S12345)
- M27  - Report SD print status
- M28  - Start SD write (M28 filename.g)
- M29  - Stop SD write
- M30 <filename> - Delete file on sd card
- M32 <dirname> create subdirectory
- M42 P<pin number> S<value 0..255> - Change output of pin P to S. Does not work on most important pins.
- M80  - Turn on power supply
- M81  - Turn off power supply
- M82  - Set E codes absolute (default)
- M83  - Set E codes relative while in Absolute Coordinates (G90) mode
- M84  - Disable steppers until next move,
        or use S<seconds> to specify an inactivity timeout, after which the steppers will be disabled.  S0 to disable the timeout.
- M85  - Set inactivity shutdown timer with parameter S<seconds>. To disable set zero (default)
- M92  - Set axisStepsPerMM - same syntax as G92
- M99 S<delayInSec> X0 Y0 Z0 - Disable motors for S seconds (default 10) for given axis.
- M104 S<temp> T<extruder> P1 F1 - Set temperature without wait. P1 = wait for moves to finish, F1 = beep when temp. reached first time
- M105 X0 - Get temperatures. If X0 is added, the raw analog values are also written.
- M112 - Emergency kill
- M115- Capabilities string
- M116 - Wait for all temperatures in a +/- 1 degree range
- M117 <message> - Write message in status row on lcd
- M119 - Report endstop status
- M140 S<temp> F1 - Set bed target temp, F1 makes a beep when temperature is reached the first time
- M163 S<extruderNum> P<weight>  - Set weight for this mixing extruder drive
- M164 S<virtNum> P<0 = dont store eeprom,1 = store to eeprom> - Store weights as virtual extruder S
- M190 - Wait for bed current temp to reach target temp.
- M200 T<extruder> D<diameter> - Use volumetric extrusion. Set D0 or omit D to disable volumetric extr. Omit T for current extruder.
- M201 - Set max acceleration in units/s^2 for print moves (M201 X1000 Y1000)
- M202 - Set max acceleration in units/s^2 for travel moves (M202 X1000 Y1000)
- M203 - Set temperture monitor to Sx
- M204 - Set PID parameter X => Kp Y => Ki Z => Kd S<extruder> Default is current extruder. NUM_EXTRUDER=Heated bed
- M205 - Output EEPROM settings
- M206 - Set EEPROM value
- M207 X<XY jerk> Z<Z Jerk> E<ExtruderJerk> - Changes current jerk values, but do not store them in eeprom.
- M209 S<0/1> - Enable/disable autoretraction
- M220 S<Feedrate multiplier in percent> - Increase/decrease given feedrate
- M221 S<Extrusion flow multiplier in percent> - Increase/decrease given flow rate
- M226 P<pin> S<state 0/1> - Wait for pin getting state S. Add X0 to init as input without pullup and X1 for input with pullup.
- M231 S<OPS_MODE> X<Min_Distance> Y<Retract> Z<Backlash> F<ReatrctMove> - Set OPS parameter
- M232 - Read and reset max. advance values
- M233 X<AdvanceK> Y<AdvanceL> - Set temporary advance K-value to X and linear term advanceL to Y
- M251 Measure Z steps from homing stop (Delta printers). S0 - Reset, S1 - Print, S2 - Store to Z length (also EEPROM if enabled)
- M280 S<mode> - Set ditto printing mode. mode: 0 = off, 1 = 1 extra extruder, 2 = 2 extra extruder, 3 = 3 extra extruders
- M281 Test if watchdog is running and working. Use M281 X0 to disable watchdog on AVR boards. Sometimes needed for boards with old bootloaders to allow reflashing.
- M300 S<Frequency> P<DurationMillis> play frequency
- M302 S<0 or 1> - allow cold extrusion. Without S parameter it will allow. S1 will disallow.
- M303 P<extruder/bed> S<printTemerature> X0 R<Repetitions>- Autodetect pid values. Use P<NUM_EXTRUDER> for heated bed. X0 saves result in EEPROM. R is number of cycles.
- M320 S<0/1> - Activate autolevel, S1 stores it in eeprom
- M321 S<0/1> - Deactivate autolevel, S1 stores it in eeprom
- M322 - Reset autolevel matrix
- M323 S0/S1 enable disable distortion correction P0 = not permanent, P1 = permanent = default
- M340 P<servoId> S<pulseInUS> R<autoOffIn ms>: servoID = 0..3, Servos are controlled by a pulse with normally between 500 and 2500 with 1500ms in center position. 0 turns servo off. R allows automatic disabling after a while.
- M350 S<mstepsAll> X<mstepsX> Y<mstepsY> Z<mstepsZ> E<mstepsE0> P<mstespE1> : Set microstepping on RAMBO board
- M355 S<0/1> - Turn case light on/off, no S = report status
- M360 - show configuration
- M400 - Wait until move buffers empty.
- M401 - Store x, y and z position.
- M402 - Go to stored position. If X, Y or Z is specified, only these coordinates are used. F changes feedrate fo rthat move.
- M450 - Reports printer mode
- M451 - Set printer mode to FFF
- M452 - Set printer mode to laser
- M453 - Set printer mode to CNC
- M460 X<minTemp> Y<maxTemp> : Set temperature range for thermistor controlled fan
- M500 Store settings to EEPROM
- M501 Load settings from EEPROM
- M502 Reset settings to the one in configuration.h. Does not store values in EEPROM!
- M513 - Clear all jam marker.
- M600 Change filament
- M601 S<1/0> - Pause extruders. Paused extrudes disable heaters and motor. Unpausing reheats extruder to old temp.
- M602 S<1/0> P<1/0>- Debug jam control (S) Disable jam control (P). If enabled it will log signal changes and will not trigger jam errors!
- M908 P<address> S<value> : Set stepper current for digipot (RAMBO board)
- M999 - Continue from fatal error. M999 S1 will create a fatal error for testing.
*/

#include "Repetier.h"
#include <SPI.h>

#if UI_DISPLAY_TYPE == DISPLAY_ARDUINO_LIB
//#include <LiquidCrystal.h> // Uncomment this if you are using liquid crystal library
#endif

void setup()
{
    Printer::setup();
}

void loop()
{
    Commands::commandLoop();
}

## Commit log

2016-07-09 [Drivers] Add win8+ and osx drivers for ch340g
2016-07-10 [Printer Parts] Add initial set of parts from S.Craig
    [Arduino_T-Slot_Mount_mod1.scad, Arduino_T-Slot_Mount_mod1.stl, LED Brackets v3.f3d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]
2016-07-15 [Printers] First printer sample firmware
    [Configuration.h]
2016-07-15 [Leonard-firmware] Updating
    [Configuration.h]
2016-07-15 Added json config file
    [Configuration.h]
2016-07-19 [Firmware] Update config for leonardo
    [Configuration.h]
2016-07-21 [Firmware] Add donatello + config json
    [Configuration.h]
2016-07-22 [Firmware] Add Bartolini/Bart config and firmware
    [Configuration.h]
2016-07-25 [Firmware] Add Michelangelo
    [Configuration.h]
2016-07-26 [Firmware] Initial ES settings
    [Configuration.h]
2016-07-26 [Firmware] ES update
    [Configuration.h]
2016-07-26 [firmware] Calder Initial
    [Configuration.h]
2016-07-29 [Firmware] Add Calder json & distortion calibration
    [Configuration.h]
2016-08-01 [Firmware] Add firmware for epstein + calibration
    [Configuration.h]
2016-12-02 add calibration test set: :
    [0.5mm-thin-wall.stl, 20mm-box.skp, 20mm-box.stl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]
2016-12-14 Sierra drivers
2016-12-14 Update calder with acme rods
    [Configuration.h, acme_z_axis_lead_screw_holder_botero-v2.stl]
2017-02-04 update configs and add dual extruder for calder
    [Configuration.h]
2018-04-11 Add z endstop and new config for donatello
    [Configuration.h, z-endstop-v1.stl]
2018-07-12 update config for don
    [Configuration.h]
2019-11-14 update donatello firmware and include calibration set
    [0.5mm-thin-wall.stl, 20mm-box.skp, 20mm-box.stl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]
2019-11-18 update pid for donatello on hydrogel gel extruder (T1)
    [Configuration.h]
2019-11-20 fix 24V for a 12v ceramic heater -- fix PID control loop
    [Configuration.h]
2019-11-20 Add fan support for donatello
    [Configuration.h]
2020-06-26 add hydrogel firmware as separate folder
    [Configuration.h]

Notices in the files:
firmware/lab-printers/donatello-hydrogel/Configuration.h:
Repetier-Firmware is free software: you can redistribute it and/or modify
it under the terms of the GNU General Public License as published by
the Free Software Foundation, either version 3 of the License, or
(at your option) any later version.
